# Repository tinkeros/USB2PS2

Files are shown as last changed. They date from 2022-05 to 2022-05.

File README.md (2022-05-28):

# USB2PS2

The goal of this project is to provide people a cheap way to use USB keyboards/mice with <a href="https://www.freedos.org/">DOS</a>/<a href="https://templeos.org">TempleOS</a>/<a href="https://github.com/tinkeros/TinkerOS">TinkerOS</a>.  Many modern motherboards provide PS/2 emulation for USB keyboards only which leaves you with no mouse support unless you are willing to connect a PS/2 mouse.  Thankfully many motherboards are still available that have PS/2 ports.  You can use this project for adding mouse support via PS/2.  Keyboard support works also.  I use it to connect my TinkerOS machine to my USB KVM which provides both keyboard and mouse through one USB connection.

I built this project in my spare time while helping test out the <a href="https://github.com/dekuNukem/USB4VC">USB4VC</a> project which provides an excellent solution for people who want to use USB keyboards/mice/gamepads with operating systems that require ADB, PS/2, serial and/or gameport inputs.  If you don't want to build it yourself, you can just <a href="https://www.tindie.com/products/dekuNukem/usb4vc-usb-inputs-on-retro-computers/">buy the USB4VC</a> and it will "just work" for DOS/TempleOS/TinkerOS and many other operating systems.

If you are a DYI kind of person who likes to tinker with 3D printing/Arduinos/PIs/electronics, then this maybe useful to you.  This is a do at your own risk project!  I am not an electrical engineer and if you do this wrong you could fry your Arduino/Computer/PI or possibly even set your house on fire.  Only play with electronics if you feel like you are up to the task and accepting of the risks.

The PS/2 keyboard code is from ps2dev, the PS/2 mouse code is code adapted from USB4VC.  The PI SD card image is a USB4VC image which has been modified to communicate with an Arduino over serial instead of a USB4VC IBM PC protocol card using SPI.

### Suggested supplies:
- Arduino Uno (or other version if you're willing to adapt the code yourself)
- Raspberry PI (PI zero is the cheapest and will work fine for this project)
- Logic level converter (convert between PI 3.3V logic levels and Arduino 5V logic levels, possibly optional)
- 2x male PS/2 to male PS/2 cables (can use 1 instead if you cut and solder, see notes below, you might be able to make your own much cheaper)
- 2x female PS/2 ports to connect to the Arduino (optional, see notes below)
- USB cables/power supplies for powering the Arduino and PI
- Micro USB to USB-A female USB adapter (if using a PI zero) and USB hub (if you want to connect multiple devices)
- Jumper wires to connect the Arduino/PI/level converter

### Required Arudino libraries:
- ps2dev (I used version 0.0.3)

### Software Installation:
Installation simply requires extracting and flashing the <a href="https://github.com/tinkeros/USB2PS2/releases/download/v0.1.1-beta/usb4vc_arduino_mod.img.xz">usb4vc_arduino_mod.img.xz</a> PI image to a micro SD card.  It will auto resize the filesystem to fill the card on first boot and then reboot.  The username/password is pi/raspberry.  
The Arduino is flashed with the sketch that can be found in <a href="https://github.com/tinkeros/USB2PS2/tree/master/ArduinoUno/pi_to_ps2_keyboard_mouse/pi_to_ps2_keyboard_mouse">ArduinoUno/pi_to_ps2_keyboard_mouse/pi_to_ps2_keyboard_mouse</a>.  Be sure to modify the defined pin numbers at the top of the sketch to the values you desire to use.

### Software and circuit connections overview:
The PI captues keyboard/mouse events from attached USB devices and sends them to the Arduino over the UART.  You might be able to make this work by connecting just 2 wires between the Arduino and PI.  The PS/2 ports are connected to data/clock pins you choose on the Arduino and two ground pins.  More details on the connection setup can be found below.  If everything is connected right after the Arduino is powered up and the PI is fully booted it should just work and automatically start relaying USB keyboard/mouse events to the Arduino which will convert them to PS/2.  PI zeros are slow and it took mine about 2 minutes to fully be up and ready the first time (due to the need to resize the filesystem and reboot).

### Supply notes:
- You can get away with no female PS/2 ports and with just one male to male PS/2 cable if it is long enough and you cut it in half and connect/solder the wires directly to the Arduino.
- You might be able to get away with just connecting the PI TX pin to the Arduino RX pin or use a simple resister/transistor based circuit to convert the logic level instead of using a level converter.  
- There are Arduino Uno clones which provide additional headers you can use to solder components onto easily.  Here is an <a href="https://github.com/tinkeros/USB2PS2/raw/master/images/ArduinoClone.jpg">example</a> of one such board I bought cheap off AliExpress.

### Recommended connections connecting the Arduino / Level Converter / PI:
  
Arduino 5V   <-> Level Converter HV  
Arduino GND  <-> Level Converter GND  
Arduino RX   <-> Level Converter HV1  
Arduino TX   <-> Level Converter HV2 (optional)  
  
PI 3.3V <-> Level Converter LV  
PI GND  <-> Level Converter GND  
PI TX   <-> Level Converter LV1  
PI RX   <-> Level Converter LV2 (optional)  
  
<p align="center">
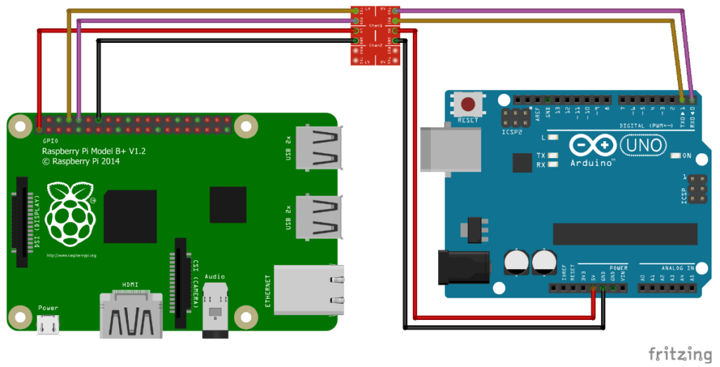
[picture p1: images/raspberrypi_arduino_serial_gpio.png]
  
</p>

### Example using a simple 2 wire connection (works for me with an Arduino Uno clone and Rasperry PI Zero W):
  
Arduino GND  <-> PI GND  
Arduino RX   <-> PI TX 

<p align="center">
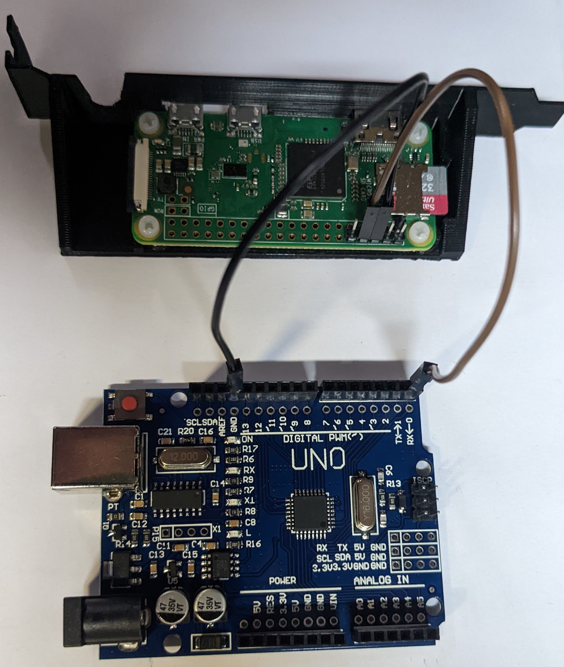
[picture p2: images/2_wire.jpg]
  
</p>

### Wiring the PS/2 ports to the Arduino:
PS/2 is bitbanged so you may use any analog or digital pins (other than those used by the UART) for PS/2 communications.  For each PS/2 connection you want to use, you need to connect a clock, data, and ground pins.  Choose whatever pins you want to use for clock and data for each device and modify the defined values for PS2_MOUSE_CLOCK_PIN, PS2_MOUSE_DATA_PIN, PS2_KEYBOARD_CLOCK_PIN, and PS2_KEYBOARD_DATA_PIN as appropriate.  You do not need to connect the 5V PS/2 pin and should not connect it.

## Powering the Arduino and PI:
- I suggest powering the Arduino from the PC using the normal USB-B to USB-A cable you use to connect it to the PC and program it with.
- I suggest powering the PI with a micro USB to USB-A cable connected to the PC if using a PI Zero W or the official PI power supply.
- I do not connect the 5V pin on any of the PS/2 connectors or use them to draw power.  I highly advise against drawing power from the PS/2 ports.

## 3D printed PCI brackets for Arduino UNO/Raspberry PI Zero:
You can contain this project nicely inside your PC if you have two free PCI slots.  There are many 3D printable PCI brackets available for Raspberry PIs and Arduinos (just search thingiverse).  I've included the two STL files I used in the STL folder <a href="https://github.com/tinkeros/USB2PS2/raw/master/STL/pci_arduino.stl">Arduino UNO PCI bracket</a> and <a href="https://github.com/tinkeros/USB2PS2/raw/master/STL/single_zero_pi_pci.stl">PI zero PCI bracket</a>  Even if you do not own a 3D printer there are many online services you can use to get someone else to print them for you cheaply.  After printing you will want to cut/drill an extra slot into one of them for the PS/2 cables to go through.  You may also have to use a knife or drill to remove some material from the brackets to make things fit nicely depending on the print quality used.

### Example Arduino / PI mounted in brackets (note extra slot cut into the PI bracket for the PS/2 cables):

<p align="center">
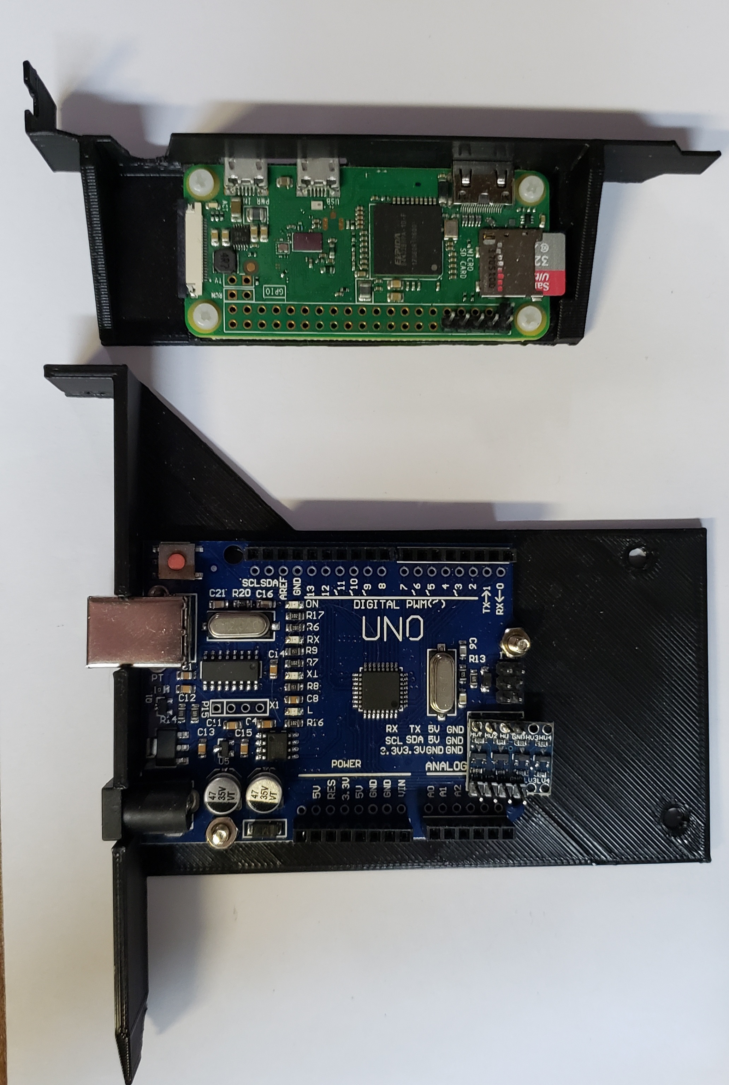
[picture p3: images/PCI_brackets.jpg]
  
</p>

### Installed setup with PS/2 cables coming out:

<p align="center">
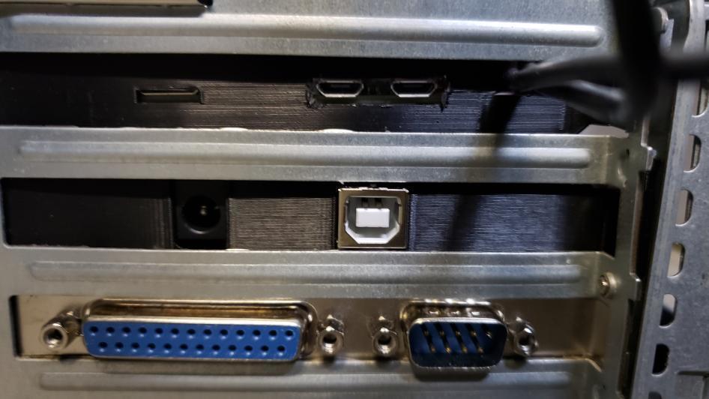
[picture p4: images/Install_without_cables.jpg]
  
</p>

### Installed setup with PS/2 cables, two USB cables powering Arduino and PI, and one micro USB to USB-A cable with a wireless USB keyboard/ mouse combo reciever:

<p align="center">
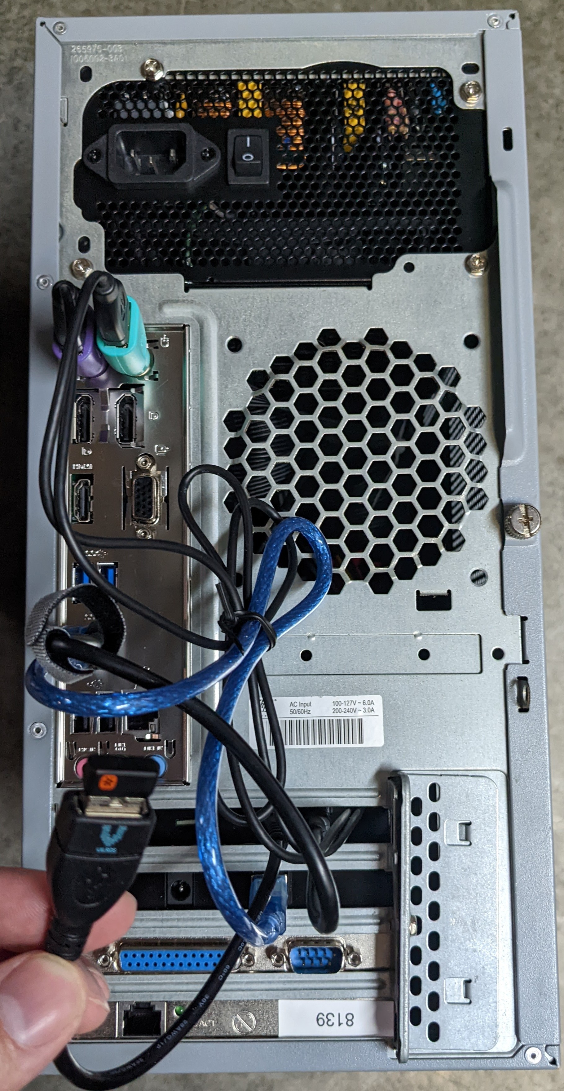
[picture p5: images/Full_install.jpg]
  
</p>

## Cheaply making PS/2 cables:
Real PS/2 cables are becoming expensive because they are rarely used and not mass produced anymore.  You are free to use them, however I would like to suggest an alternative that may be much cheaper and may work better for this particular project.  There is an abundance of cheap to obtain PS/2 to USB adapters and USB-A to A cables (just check eBay).  You can use these to make PS/2 male to male cables or for the case of this project you can simply cut the USB cord and connect/solder the proper wires to the proper Arduino pins.  If you have some old USB cables of laying around, you can skip buying an A-A cable, buy the PS/2 male to USB-A female adapters only and just chop one end off your existing cables.  Just know that whatever cable you use must have both the power and data wires for it to work.  You will need to connect the wires which go to the ground, clock, and data pins of the PS/2 connector.  These should be the black, green and white wires, but be sure to check the connections just to be sure your cable is not wired differently!

<p align="center">
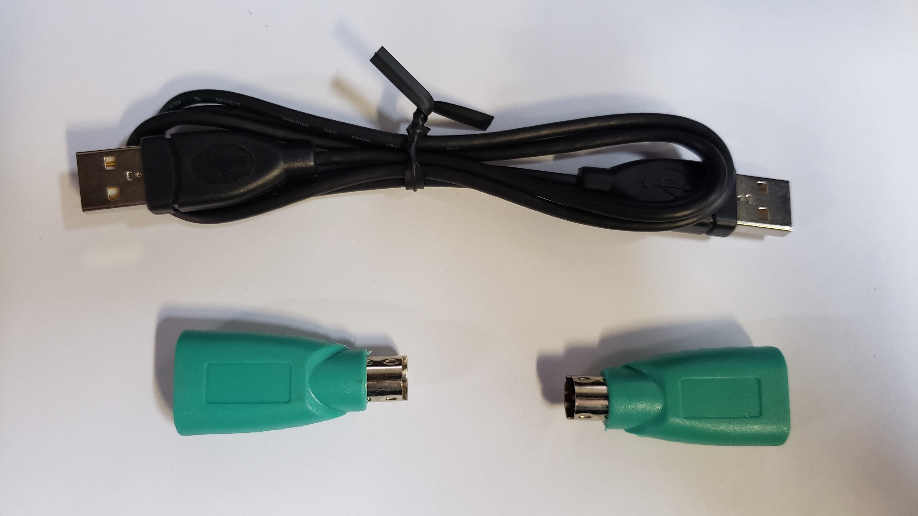
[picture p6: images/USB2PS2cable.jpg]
  
</p>

### Acknowledgements:
<a href="https://github.com/dekuNukem/USB4VC">USB4VC project</a>

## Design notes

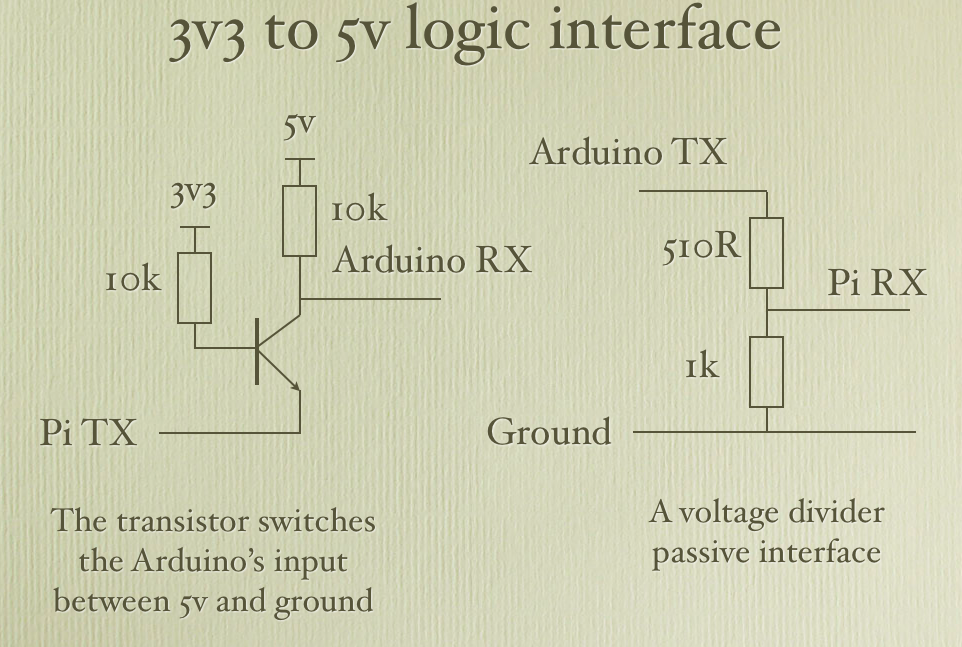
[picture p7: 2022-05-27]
images/ardtopi.png

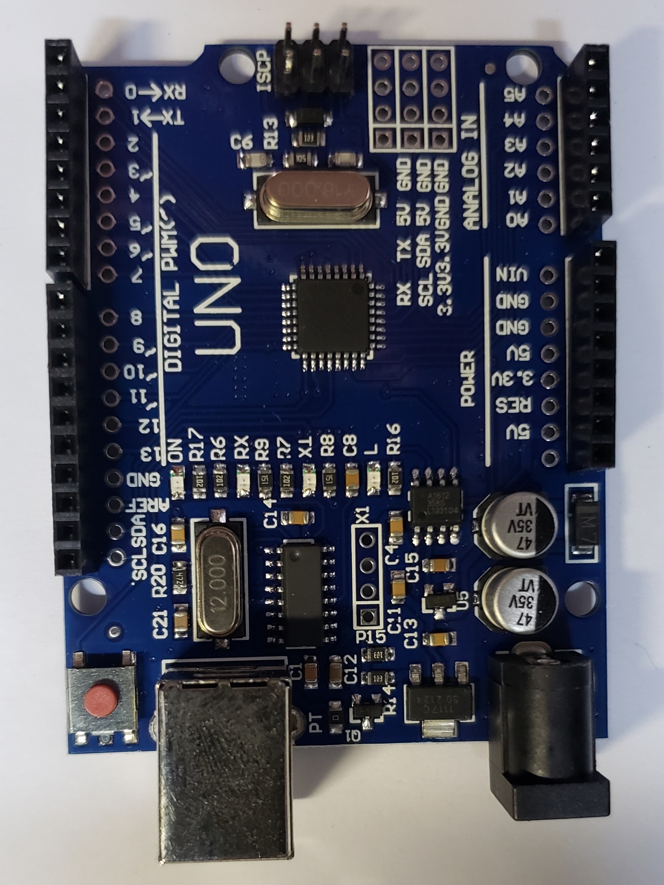
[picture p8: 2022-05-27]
images/ArduinoClone.jpg

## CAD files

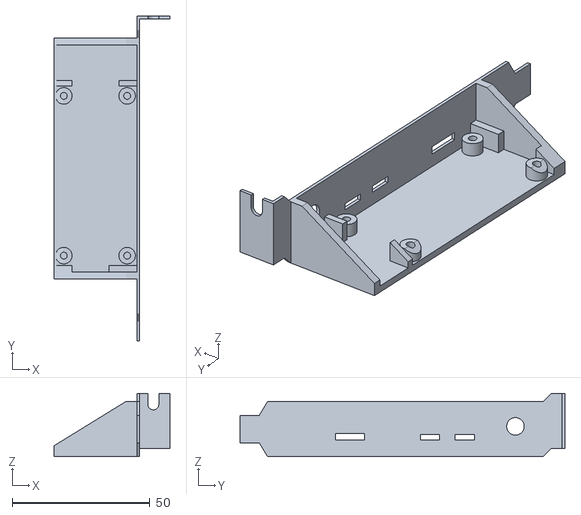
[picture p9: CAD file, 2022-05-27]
STL/single_zero_pi_pci.stl
42.0 x 118.0 x 23.0

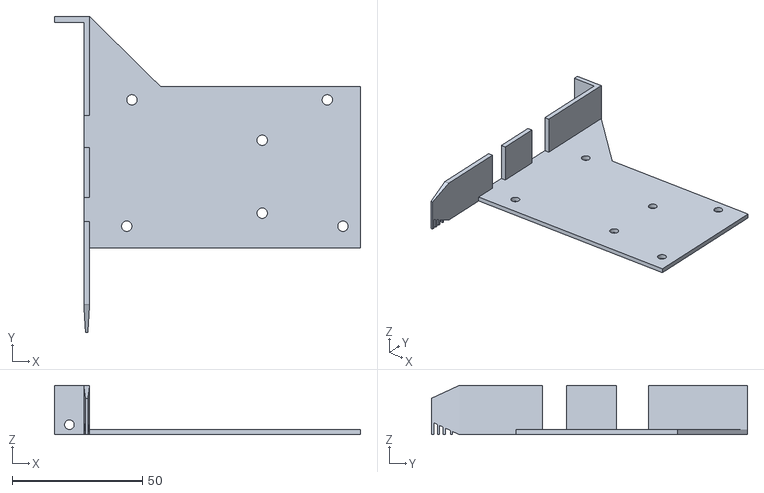
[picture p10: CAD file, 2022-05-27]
STL/pci_arduino.stl
117.5 x 121.3 x 19.0

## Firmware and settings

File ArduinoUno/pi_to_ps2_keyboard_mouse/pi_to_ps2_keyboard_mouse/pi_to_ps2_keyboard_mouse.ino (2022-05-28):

/*
   This file includes code from the USB4VC project
   which has been modifed to work on an Arduino instead
   of the STM microcontroller the protocol board uses
*/

#include <ps2dev.h>
#include "ps2mouse.h"

#define PS2_MOUSE_CLOCK_PIN 2
#define PS2_MOUSE_DATA_PIN  3

#define PS2_KEYBOARD_CLOCK_PIN 4
#define PS2_KEYBOARD_DATA_PIN  5

#define SPI_MOSI_MAGIC 0xde
#define SPI_MOSI_MSG_TYPE_KEYBOARD_EVENT 8
#define SPI_MOSI_MSG_TYPE_MOUSE_EVENT 9
#define SPI_MOSI_MSG_TYPE_GAMEPAD_EVENT_RAW 10
#define SPI_MOSI_MSG_TYPE_GAMEPAD_EVENT_MAPPED 11

#define LINUX_KEYCODE_TO_PS2_SCANCODE_SINGLE_SIZE 89
#define LINUX_KEYCODE_TO_PS2_SCANCODE_SPECIAL_SIZE 32

#define CODE_UNUSED 0xff
#define PS2KB_WRITE_DEFAULT_TIMEOUT_MS 20
#define MOUSE_AVG 20

typedef struct
{
  uint8_t button_1;
  uint8_t button_2;
  uint8_t button_3;
  uint8_t button_4;
  uint8_t button_lt;
  uint8_t button_rt;
  uint8_t button_lt2;
  uint8_t button_rt2;
  uint8_t axis_x;
  uint8_t axis_y;
  uint8_t axis_rx;
  uint8_t axis_ry;
} gamepad_event;

const uint8_t linux_keycode_to_ps2_scancode_lookup_single_byte_codeset2[LINUX_KEYCODE_TO_PS2_SCANCODE_SINGLE_SIZE] =
{
  CODE_UNUSED, // KEY_RESERVED       0
  0x76, // KEY_ESC            1
  0x16, // KEY_1          2
  0x1E, // KEY_2          3
  0x26, // KEY_3          4
  0x25, // KEY_4          5
  0x2E, // KEY_5          6
  0x36, // KEY_6          7
  0x3D, // KEY_7          8
  0x3E, // KEY_8          9
  0x46, // KEY_9          10
  0x45, // KEY_0          11
  0x4E, // KEY_MINUS      12
  0x55, // KEY_EQUAL      13
  0x66, // KEY_BACKSPACE      14
  0x0D, // KEY_TAB            15
  0x15, // KEY_Q          16
  0x1D, // KEY_W          17
  0x24, // KEY_E          18
  0x2D, // KEY_R          19
  0x2C, // KEY_T          20
  0x35, // KEY_Y          21
  0x3C, // KEY_U          22
  0x43, // KEY_I          23
  0x44, // KEY_O          24
  0x4D, // KEY_P          25
  0x54, // KEY_LEFTBRACE      26
  0x5B, // KEY_RIGHTBRACE     27
  0x5A, // KEY_ENTER      28
  0x14, // KEY_LEFTCTRL       29
  0x1C, // KEY_A          30
  0x1B, // KEY_S          31
  0x23, // KEY_D          32
  0x2B, // KEY_F          33
  0x34, // KEY_G          34
  0x33, // KEY_H          35
  0x3B, // KEY_J          36
  0x42, // KEY_K          37
  0x4B, // KEY_L          38
  0x4C, // KEY_SEMICOLON      39
  0x52, // KEY_APOSTROPHE     40
  0x0E, // KEY_GRAVE      41
  0x12, // KEY_LEFTSHIFT      42
  0x5D, // KEY_BACKSLASH      43
  0x1A, // KEY_Z          44
  0x22, // KEY_X          45
  0x21, // KEY_C          46
  0x2A, // KEY_V          47
  0x32, // KEY_B          48
  0x31, // KEY_N          49
  0x3A, // KEY_M          50
  0x41, // KEY_COMMA      51
  0x49, // KEY_DOT            52
  0x4A, // KEY_SLASH      53
  0x59, // KEY_RIGHTSHIFT     54
  0x7C, // KEY_KPASTERISK     55
  0x11, // KEY_LEFTALT        56
  0x29, // KEY_SPACE      57
  0x58, // KEY_CAPSLOCK       58
  0x05, // KEY_F1         59
  0x06, // KEY_F2         60
  0x04, // KEY_F3         61
  0x0C, // KEY_F4         62
  0x03, // KEY_F5         63
  0x0B, // KEY_F6         64
  0x83, // KEY_F7         65
  0x0A, // KEY_F8         66
  0x01, // KEY_F9         67
  0x09, // KEY_F10            68
  0x77, // KEY_NUMLOCK        69
  0x7E, // KEY_SCROLLLOCK     70
  0x6C, // KEY_KP7            71
  0x75, // KEY_KP8            72
  0x7D, // KEY_KP9            73
  0x7B, // KEY_KPMINUS        74
  0x6B, // KEY_KP4            75
  0x73, // KEY_KP5            76
  0x74, // KEY_KP6            77
  0x79, // KEY_KPPLUS     78
  0x69, // KEY_KP1            79
  0x72, // KEY_KP2            80
  0x7A, // KEY_KP3            81
  0x70, // KEY_KP0            82
  0x71, // KEY_KPDOT      83
  CODE_UNUSED, // KEY_UNUSED     84
  CODE_UNUSED, // KEY_ZENKAKUHANKAKU 85
  0x61, // KEY_102ND      86
  0x78, // KEY_F11            87
  0x07, // KEY_F12            88
};

const uint8_t linux_keycode_to_ps2_scancode_lookup_special_codeset2[LINUX_KEYCODE_TO_PS2_SCANCODE_SPECIAL_SIZE] =
{
  0x5A, // KPENTER    96
  0x14, // KEY_RIGHTCTRL    97
  0x4A, // KEY_KPSLASH    98
  CODE_UNUSED, // 99
  0x11, // KEY_RIGHTALT   100
  CODE_UNUSED, // 101
  0x6C, // KEY_HOME   102
  0x75, // KEY_UP     103
  0x7D, // KEY_PAGEUP   104
  0x6B, // KEY_LEFT   105
  0x74, // KEY_RIGHT    106
  0x69, // KEY_END      107
  0x72, // KEY_DOWN   108
  0x7A, // KEY_PAGEDOWN   109
  0x70, // KEY_INSERT   110
  0x71, // KEY_DELETE   111
  CODE_UNUSED, // KEY_MACRO   112
  CODE_UNUSED, // KEY_MUTE    113
  CODE_UNUSED, // KEY_VOLUMEDOWN    114
  CODE_UNUSED, // KEY_VOLUMEUP    115
  CODE_UNUSED, // KEY_POWER   116
  CODE_UNUSED, // KEY_KPEQUAL   117
  CODE_UNUSED, // KEY_KPPLUSMINUS   118
  CODE_UNUSED, // KEY_PAUSE   119
  CODE_UNUSED, // KEY_SCALE   120
  CODE_UNUSED, // KEY_KPCOMMA   121
  CODE_UNUSED, // KEY_HANGEUL   122
  CODE_UNUSED, // KEY_HANJA   123
  CODE_UNUSED, // KEY_YEN     124
  0x1F, // KEY_LEFTMETA   125
  0x27, // KEY_RIGHTMETA    126
  0x2F, // KEY_COMPOSE    127
};


static uint8_t pkt[32];

static mouse_event latest_mouse_event;
static mouse_event null_mouse_event;
static gamepad_event latest_gamepad_event;
static uint8_t enabled = 1;

static uint32_t last_mouse = 0;
static uint8_t cur_buttons[3];
static uint8_t last_buttons[3];
static uint8_t mouse_cnt = 0;
static volatile int mouse_dx = 0;
static volatile int mouse_dy = 0;

static uint8_t ps2mouse_host_cmd = 0, ps2mouse_bus_status = 0;
static ps2_outgoing_buf my_ps2_outbuf;

static uint32_t last_kb_status_check;
static uint32_t last_ms_status_check;

static uint8_t kbd_ms = 0;


PS2dev keyboard(PS2_KEYBOARD_CLOCK_PIN, PS2_KEYBOARD_DATA_PIN);

uint8_t ps2kb_press_key_scancode_2(uint8_t linux_keycode, uint8_t linux_keyvalue)
{
  // linux_keyvalue: release 0 press 1 autorepeat 2
  uint8_t lookup_result;

  if (linux_keycode < LINUX_KEYCODE_TO_PS2_SCANCODE_SINGLE_SIZE)
  {
    lookup_result = linux_keycode_to_ps2_scancode_lookup_single_byte_codeset2[linux_keycode];
    if (lookup_result == CODE_UNUSED)
      return 2;
    if (linux_keyvalue)
    {
      keyboard.write(lookup_result);
    }
    else
    {
      keyboard.write(0xf0);
      keyboard.write(lookup_result);
    }
    return 0;
  }

  if (linux_keycode >= 96 && linux_keycode <= 127)
  {
    lookup_result = linux_keycode_to_ps2_scancode_lookup_special_codeset2[linux_keycode - 96];
    if (lookup_result == CODE_UNUSED)
      return 2;
    if (linux_keyvalue)
    {
      keyboard.write(0xe0);
      keyboard.write(lookup_result);
    }
    else
    {
      keyboard.write(0xe0);
      keyboard.write(0xf0);
      keyboard.write(lookup_result);
    }
    return 0;
  }
  return 0;
}

static void process_keyboard_pkt(uint8_t *kb_pkt)
{
  int i;
  // Additional pkt validation
  if (0xaa != kb_pkt[3])
    return;

  ps2kb_press_key_scancode_2(kb_pkt[4], kb_pkt[6]);
}

static int16_t byte_to_int16_t(uint8_t lsb, uint8_t msb)
{
  return (int16_t)((msb << 8) | lsb);
}

static void ps2mouse_update(void)
{
  ps2mouse_bus_status = ps2mouse_get_bus_status();
  if (ps2mouse_bus_status == PS2_BUS_INHIBIT)
  {
    ps2mouse_release_lines();
    return;
  }
  else if (ps2mouse_bus_status == PS2_BUS_REQ_TO_SEND)
  {
    ps2mouse_read(&ps2mouse_host_cmd, 10);
    ps2mouse_host_req_reply(ps2mouse_host_cmd, &null_mouse_event);
    return;
  }

  if (!latest_mouse_event.button_extra) {
    // nothing to send now
    return;
  }

  mouse_event* this_mouse_event = &latest_mouse_event;

  if (ps2mouse_get_outgoing_data(this_mouse_event, &my_ps2_outbuf))
  {
    // if return value is not 0, no need to send out packets
    return;
  }

  // only pop the item if sending is complete
  if (ps2mouse_send_update(&my_ps2_outbuf) == 0)
  {
    // send is ok
    latest_mouse_event.button_extra = 0;
  }
}

static void process_mouse_pkt(uint8_t *ms_pkt)
{
  int i, res = 0;
  int8_t *ms_pkt_signed = (int8_t*)ms_pkt;
  latest_mouse_event.button_extra = 0;

  // Additional pkt validation
  if (0x55 != ms_pkt[3])
    return;

  // Modified USB4VC packet pruned to 16 bytes
  //latest_mouse_event.movement_x = byte_to_int16_t(ms_pkt[4], ms_pkt[5]);
  //latest_mouse_event.movement_y = -1 * byte_to_int16_t(ms_pkt[6], ms_pkt[7]);
  latest_mouse_event.movement_x = ms_pkt_signed[4];
  latest_mouse_event.movement_y = ms_pkt_signed[5];
  latest_mouse_event.scroll_vertical = 0;
  latest_mouse_event.scroll_horizontal = 0;
  cur_buttons[0] = latest_mouse_event.button_left = ms_pkt[6] % 4;
  cur_buttons[1] = latest_mouse_event.button_right = ms_pkt[6] / 4;
  //cur_buttons[2]=latest_mouse_event.button_middle = ms_pkt[15];


  if ( ((0 == latest_mouse_event.movement_x) && (0 == latest_mouse_event.movement_y))
       && (cur_buttons[0] == last_buttons[0])
       && (cur_buttons[1] == last_buttons[1]) ) {
    // skip this redundant packet
    return;
  }

  latest_mouse_event.button_side = 0;
  latest_mouse_event.button_extra = 1;  // using this as a "this event needs to be sent flag"

  last_buttons[0] = cur_buttons[0];
  last_buttons[1] = cur_buttons[1];
  ps2mouse_update();

}

static void process_gamepad_pkt(uint8_t *backup_spi1_recv_buf)
{
  // Modified USB4VC packet pruned to 16 bytes
  latest_gamepad_event.button_1 = backup_spi1_recv_buf[4];
  latest_gamepad_event.button_2 = backup_spi1_recv_buf[5];
  latest_gamepad_event.button_3 = backup_spi1_recv_buf[6];
  latest_gamepad_event.button_4 = backup_spi1_recv_buf[7];
  latest_gamepad_event.button_lt = 0;
  latest_gamepad_event.button_rt = 0;
  latest_gamepad_event.button_lt2 = 0;
  latest_gamepad_event.button_rt2 = 0;
  latest_gamepad_event.axis_x = backup_spi1_recv_buf[8];
  latest_gamepad_event.axis_y = backup_spi1_recv_buf[9];
  latest_gamepad_event.axis_rx = backup_spi1_recv_buf[10];
  latest_gamepad_event.axis_ry = backup_spi1_recv_buf[11];
}

void setup() {
  pinMode(LED_BUILTIN, OUTPUT);

  keyboard.keyboard_init();
  digitalWrite(LED_BUILTIN, HIGH);
  Serial.begin(57600);

  while (!Serial) {
    ; // wait for serial port to connect. Needed for native USB port only
  }

  delay(200);

  cur_buttons[0] = 0;
  cur_buttons[1] = 0;
  cur_buttons[2] = 0;
  last_buttons[0] = 0;
  last_buttons[1] = 0;
  last_buttons[2] = 0;
  mouse_dx = 0;
  mouse_dy = 0;

  null_mouse_event.movement_x = 0;
  null_mouse_event.movement_y = 0;
  null_mouse_event.scroll_vertical = 0;
  null_mouse_event.scroll_horizontal = 0;
  null_mouse_event.button_left = 0;
  null_mouse_event.button_middle = 0;
  null_mouse_event.button_right = 0;
  null_mouse_event.button_side = 0;
  null_mouse_event.button_extra = 0;

  latest_mouse_event.button_extra = 0;

  ps2mouse_init(PS2_MOUSE_CLOCK_PIN, PS2_MOUSE_CLOCK_PIN, PS2_MOUSE_DATA_PIN, PS2_MOUSE_DATA_PIN);
  ps2mouse_enable_reporting();

  last_kb_status_check = millis();
  last_ms_status_check = millis();
  digitalWrite(LED_BUILTIN, LOW);
}

void loop() {
  uint8_t inByte, inByte2, leds;
  int i, res;

  if (millis() - last_kb_status_check > 5)
  {
    if (keyboard.keyboard_handle(&leds)) {
      //Serial.print('LEDS');
      //Serial.print(leds, HEX);
      digitalWrite(LED_BUILTIN, leds);
    }
    last_kb_status_check = millis();
  }
  else if (millis() - last_ms_status_check > 5) {
    ps2mouse_update();
    last_ms_status_check = millis();
  }

}

void serialEvent()
{
  int i, tmp;
  uint8_t inByte, inByte2, inByte3, inByte4;


  if (Serial.available() > 5) {
    inByte = Serial.read();
    inByte2 = Serial.read();
    inByte3 = Serial.read();
    inByte4 = Serial.read();

    if ((SPI_MOSI_MAGIC != inByte) || ( 0 != inByte2 ) || (inByte3 > SPI_MOSI_MSG_TYPE_GAMEPAD_EVENT_MAPPED)) {

      while (Serial.available() > 0) {
        inByte = inByte2;
        inByte2 = inByte3;
        inByte3 = inByte4;
        inByte4 = Serial.read();
        if ((SPI_MOSI_MAGIC == inByte) && ( 0 == inByte2 ) && (inByte3 <= SPI_MOSI_MSG_TYPE_GAMEPAD_EVENT_MAPPED)) {
          if ((inByte4 == 0x55) || (inByte4 == 0xaa)) {
            goto pkt_start;
          }
        }
      }
    }
    else {
pkt_start:
      pkt[0] = inByte;
      pkt[1] = inByte2;
      pkt[2] = inByte3;
      pkt[3] = inByte4;
      i = 4;
      // Got what seems to be a valid packet, read more bytes and validate
      while (i < 7)
      {
        while (!Serial.available()) {
          delayMicroseconds(10);
        }
        tmp = Serial.read();
        if (tmp >= 0) {
          pkt[i++] = tmp;
        }
        else {
          // Bail out if we don't receive more bytes in a timely manner
          break;
        }
      }
      if (i != 7) {
        // Additional validation, if we get here things are not
        // looking right so we flush the serial port and then
        // wait for the next good packet
        while (Serial.available() > 0) {
          inByte = Serial.read();
        }
      }
      else {
        // It appears we got a "good" packet, first

        // Handle packet
        if (SPI_MOSI_MSG_TYPE_KEYBOARD_EVENT > pkt[2])
        {
          // We got an unknown event that isn't implemented by this sketch
        }
        else if (SPI_MOSI_MSG_TYPE_KEYBOARD_EVENT == pkt[2])
        {
          process_keyboard_pkt(pkt);
        }
        else if (SPI_MOSI_MSG_TYPE_MOUSE_EVENT == pkt[2])
        {

          // try to clear out left over mouse events first (if any)
          if (latest_mouse_event.button_extra) {
            ps2mouse_update();
          }
          if (!latest_mouse_event.button_extra) {
            process_mouse_pkt(pkt);
          }
        }
        else if (SPI_MOSI_MSG_TYPE_GAMEPAD_EVENT_MAPPED == pkt[2])
        {
          process_gamepad_pkt(pkt);
        }
        else {
          // We got an unknown event that isn't implemented by this sketch
        }
      }
    }
  }
}

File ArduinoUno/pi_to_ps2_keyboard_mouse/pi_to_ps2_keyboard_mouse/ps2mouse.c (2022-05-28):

/*
   This file includes code from the USB4VC project
   which has been modifed to work on an Arduino instead
   of the STM microcontroller the protocol board uses
*/

#include <stdio.h>
#include <string.h>
#include <stdlib.h>
#include <stdint.h>
#include "ps2mouse.h"

// https://wiki.osdev.org/PS/2_Mouse

#define CLKHALF 18
#define CLKFULL 36
//#define CLKHALF 20
//#define CLKFULL 40
#define BYTEWAIT 700
#define BYTEWAIT_END 250
#define PS2MOUSE_BUS_TIMEOUT_MS 30
#define CODE_UNUSED 0xff
#define PS2MOUSE_WRITE_DEFAULT_TIMEOUT_MS 20

#define PS2MOUSE_MODE_STREAM 0
#define PS2MOUSE_MODE_REMOTE 1
#define PS2MOUSE_MODE_WRAP 2

int ps2mouse_clk_port;
uint16_t ps2mouse_clk_pin;

int ps2mouse_data_port;
uint16_t ps2mouse_data_pin;
uint8_t ps2mouse_data_reporting_enabled;
uint8_t ps2mouse_sampling_rate;
uint8_t ps2mouse_resolution;
uint8_t ps2mouse_scale;
#define SAMPLE_RATE_HISTORY_BUF_SIZE 8
uint8_t sample_rate_history[SAMPLE_RATE_HISTORY_BUF_SIZE];
uint8_t sample_rate_history_index;
uint8_t mouse_device_id;
uint8_t ps2mouse_current_mode;
uint8_t ps2mouse_prev_mode;
uint8_t x_accumulator, y_accumulator, scroll_accumulator;

#define GPIO_PIN_SET 1
#define GPIO_PIN_RESET 0

void HAL_GPIO_WritePin(int port, int pin, int val);
uint8_t HAL_GPIO_ReadPin(int port, int pin);

void HAL_GPIO_WritePin(int port, int pin, int val)
{
  pinMode(pin, OUTPUT);
  digitalWrite(pin, val);
}

uint8_t HAL_GPIO_ReadPin(int port, int pin)
{
  pinMode(pin, INPUT_PULLUP);
  //delayMicroseconds(1);
  return digitalRead(pin);
}

uint32_t HAL_GetTick()
{
  return millis();
}

void delay_us(uint32_t us)
{
  delayMicroseconds(us);
}

#define PS2MOUSE_PACKET_SIZE_GENERIC 3
#define PS2MOUSE_PACKET_SIZE_INTELLIMOUSE 4

#define PS2MOUSE_CLK_HI() HAL_GPIO_WritePin(ps2mouse_clk_port, ps2mouse_clk_pin, GPIO_PIN_SET)
#define PS2MOUSE_CLK_LOW() HAL_GPIO_WritePin(ps2mouse_clk_port, ps2mouse_clk_pin, GPIO_PIN_RESET)

#define PS2MOUSE_DATA_HI() HAL_GPIO_WritePin(ps2mouse_data_port, ps2mouse_data_pin, GPIO_PIN_SET)
#define PS2MOUSE_DATA_LOW() HAL_GPIO_WritePin(ps2mouse_data_port, ps2mouse_data_pin, GPIO_PIN_RESET)

#define PS2MOUSE_READ_DATA_PIN() HAL_GPIO_ReadPin(ps2mouse_data_port, ps2mouse_data_pin)
#define PS2MOUSE_READ_CLK_PIN() HAL_GPIO_ReadPin(ps2mouse_clk_port, ps2mouse_clk_pin)

#define PS2MOUSE_SENDACK() ps2mouse_write_delay_start(0xFA, PS2MOUSE_WRITE_DEFAULT_TIMEOUT_MS)


void ps2mouse_release_lines(void)
{
  PS2MOUSE_CLK_HI();
  PS2MOUSE_DATA_HI();
  pinMode(ps2mouse_clk_pin, INPUT_PULLUP);
  pinMode(ps2mouse_data_pin, INPUT_PULLUP);
}

void reset_accumulators(void)
{
  x_accumulator = 0;
  y_accumulator = 0;
  scroll_accumulator = 0;
}

void ps2mouse_restore_defaults(void)
{
  ps2mouse_sampling_rate = 100;
  ps2mouse_resolution = 2;
  ps2mouse_scale = 1;
  ps2mouse_data_reporting_enabled = 0;
  ps2mouse_current_mode = PS2MOUSE_MODE_STREAM;
  ps2mouse_prev_mode = PS2MOUSE_MODE_STREAM;
  reset_accumulators();
}

void ps2mouse_enable_reporting(void)
{
  ps2mouse_data_reporting_enabled = 1;
}

void ps2mouse_reset(void)
{
  ps2mouse_restore_defaults();
  sample_rate_history_index = 0;
  memset(sample_rate_history, 0, SAMPLE_RATE_HISTORY_BUF_SIZE);
  mouse_device_id = 0;
}

void ps2mouse_init(int clk_port, uint16_t clk_pin, int data_port, uint16_t data_pin)
{
  ps2mouse_clk_port = clk_port;
  ps2mouse_clk_pin = clk_pin;
  ps2mouse_data_port = data_port;
  ps2mouse_data_pin = data_pin;
  ps2mouse_reset();
  ps2mouse_release_lines();
}

uint8_t ps2mouse_get_bus_status(void)
{
  if (PS2MOUSE_READ_DATA_PIN() == GPIO_PIN_SET && PS2MOUSE_READ_CLK_PIN() == GPIO_PIN_SET)
    return PS2_BUS_IDLE;
  if (PS2MOUSE_READ_DATA_PIN() == GPIO_PIN_SET && PS2MOUSE_READ_CLK_PIN() == GPIO_PIN_RESET)
    return PS2_BUS_INHIBIT;
  if (PS2MOUSE_READ_DATA_PIN() == GPIO_PIN_RESET && PS2MOUSE_READ_CLK_PIN() == GPIO_PIN_SET)
    return PS2_BUS_REQ_TO_SEND;
  return PS2_BUS_UNKNOWN;
}

uint8_t ps2mouse_read(uint8_t* result, uint8_t timeout_ms)
{
  uint16_t data = 0x00;
  uint16_t bit = 0x01;

  uint32_t ps2mouse_wait_start = HAL_GetTick();
  while (ps2mouse_get_bus_status() != PS2_BUS_REQ_TO_SEND)
  {
    if (HAL_GetTick() - ps2mouse_wait_start >= timeout_ms)
      return 1;
  }

  delay_us(CLKHALF);
  PS2MOUSE_CLK_LOW();
  delay_us(CLKFULL);
  PS2MOUSE_CLK_HI();
  delay_us(CLKHALF);

  while (bit < 0x0100)
  {
    if (PS2MOUSE_READ_DATA_PIN() == GPIO_PIN_SET)
      data = data | bit;
    bit = bit << 1;
    delay_us(CLKHALF);
    PS2MOUSE_CLK_LOW();
    delay_us(CLKFULL);
    PS2MOUSE_CLK_HI();
    delay_us(CLKHALF);
  }

  // stop bit
  delay_us(CLKHALF);
  PS2MOUSE_CLK_LOW();
  delay_us(CLKFULL);
  PS2MOUSE_CLK_HI();
  delay_us(CLKHALF);

  delay_us(CLKHALF);
  PS2MOUSE_DATA_LOW();
  PS2MOUSE_CLK_LOW();
  delay_us(CLKFULL);
  PS2MOUSE_CLK_HI();
  delay_us(CLKHALF);
  PS2MOUSE_DATA_HI();

  ps2mouse_release_lines();

  *result = data & 0xFF;
  return 0;
}

uint8_t ps2mouse_wait_for_idle(uint8_t timeout_ms)
{
  uint32_t ps2mouse_wait_start = HAL_GetTick();
  while (ps2mouse_get_bus_status() != PS2_BUS_IDLE)
  {
    if (HAL_GetTick() - ps2mouse_wait_start >= timeout_ms)
      return 1;
  }
  return 0;
}

uint8_t ps2mouse_write_delay_start(uint8_t data, uint8_t timeout_ms)
{
  if (ps2mouse_wait_for_idle(timeout_ms) != 0)
    return 1;
  delay_us(BYTEWAIT);
  return ps2mouse_write_nowait(data);
}

uint8_t ps2mouse_write(uint8_t data, uint8_t timeout_ms)
{
  if (ps2mouse_wait_for_idle(timeout_ms) != 0)
    return 1;
  return ps2mouse_write_nowait(data);
}
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
